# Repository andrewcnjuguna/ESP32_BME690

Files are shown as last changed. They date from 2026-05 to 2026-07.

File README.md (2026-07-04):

# ESP32_BME690

Multi-room ESP32-S3 environmental sensor node that streams air-quality data
to a Node.js server over Wi-Fi. Built around the Bosch BME690 with auxiliary
light, sound and battery monitoring.

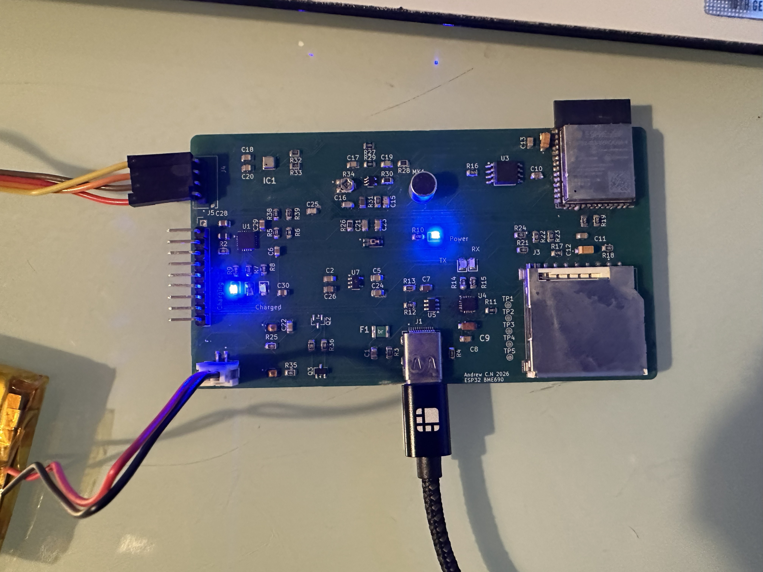
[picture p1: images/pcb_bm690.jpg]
PCB


## Hardware

- ESP32-S3-WROOM-1 module
- Bosch **BME690** (I2C) — temperature, humidity, pressure, IAQ, CO2eq, bVOC
- SH1106 0.96" OLED (I2C)
- TEMT6000 ambient light sensor
- Analog MEMS microphone (sound level)
- 1-cell LiPo with 1M/1M voltage divider on the battery rail
- USB-C power / programming
- Status LED

KiCad project lives in [hardware/kicad/](hardware/kicad/).

### Pin map

| Function | GPIO |
|---|---|
| I2C SDA | 8 |
| I2C SCL | 9 |
| Status LED  | 2 |
| Light sensor (TEMT6000) | 5 |
| Microphone  | 4 |
| VBAT sense  | 1 |

## Firmware

Sketches live in [firmware/](firmware/).

- `ESP32_BME690_usb/` — main node firmware
- `battery_level/`, `light_sensor_test/`, `sound_sensor/` — bring-up sketches

### Setup

1. Open `firmware/ESP32_BME690_usb/` in the Arduino IDE.
2. Copy `secrets.h.example` → `secrets.h` and fill in your Wi-Fi credentials
   and server URL. `secrets.h` is gitignored.
3. Install required libraries: `Adafruit GFX`, `Adafruit SH110X`,
   `BSEC2` (Bosch), `ArduinoJson`, `ArduinoOTA`.
4. Build & flash. The `locationID` constant in the sketch tags this node's
   data on the server (e.g. `Kitchen`, `Living_Room`).

### Node web page (port 80)

Each node runs its own tiny status page at `http://<node-ip>/`
(auto-refreshes every 5 s). It shows the live BSEC readings, light / sound /
battery, **WiFi signal** (RSSI in dBm, an approximate 0–100 % quality, and a
label Excellent/Good/Fair/Weak/Poor), and the SD-log status. If the SD card
is mounted it also links `http://<node-ip>/datalog.csv` to download the full
log.

The node's IP is printed on the serial console at boot
(`[INFO] Web UI at http://...`).

WiFi is self-healing: if the router is down at boot (or the link drops
later), the node keeps logging to SD and retries the connection every 30 s
in the background; OTA and the web page start automatically as soon as the
first connection succeeds — no reboot needed.

### Data upload

Every 3 s BSEC cycle the node POSTs a JSON snapshot to `SERVER_URL`
(`/sensor-data` on the dashboard server). The payload includes `location`,
all sensor channels, and the WiFi link quality (`rssi` in dBm plus a derived
`wifiPercent`). Nodes running older firmware simply omit the WiFi fields —
the dashboard shows "not reported (update firmware)" for them.

## Server (dashboard)

A small Node/Express app in [server/](server/) collects POSTs from each node
and serves a per-room dashboard.

```bash
cd server
npm install express
node server.js
```

Then point a browser at `http://<host>:3000`.

- `POST /sensor-data` — nodes push their JSON snapshot here.
- `GET /data` — latest snapshot of every room, as JSON.
- `GET /` — dashboard. Room boxes are created dynamically from whatever
  `location` tags have reported, so adding a node needs **no server change**.
  Each box shows the air-quality channels plus battery and WiFi signal
  quality for that node.

The `pi_server` notes file documents the systemd / iptables setup used on
the home Raspberry Pi.

## Data logging & plotting

### SD card log

The node averages its 3 s BSEC samples and appends **one CSV row per minute**
to `/datalog.csv` on the SD card:

```
boot_id,uptime_s,epoch,synced,temp_c,hum_pct,press_hpa,iaq,iaq_acc,
co2_ppm,voc_ppm,lux,sound_db,sound_avg,sound_peak,batt_v,batt_pct
```

- `boot_id` — power-session counter (persisted in EEPROM), groups rows from
  one uninterrupted run.
- `uptime_s` — seconds since boot (monotonic, rollover-safe).
- `epoch` / `synced` — Unix time and whether NTP had synced when the row was
  written. Rows logged *before* the sync have `epoch=0`, but their true time
  is still recoverable (see below).
- `iaq_acc` — BSEC accuracy 0–3; air-quality values below your chosen
  threshold are warm-up noise.

Grab the file over WiFi from `http://<node-ip>/datalog.csv`, or pull the
card.

### Plotting with `analysis/plot_datalog.py`

```bash
pip install pandas matplotlib
python analysis/plot_datalog.py datalog.csv            # plot a local file
python analysis/plot_datalog.py --ip 192.168.0.65      # fetch straight from the node
python analysis/plot_datalog.py datalog.csv -o out.png # save instead of showing
python analysis/plot_datalog.py datalog.csv --last 48  # last 48 h only
python analysis/plot_datalog.py datalog.csv --min-accuracy 3  # strict AQ filter
```

The script produces six stacked, time-aligned panels: temp+humidity,
pressure, IAQ, CO₂eq+VOCeq, light+sound, and battery. Under the hood it:

1. **Reconstructs absolute time.** For each `boot_id` it derives
   `boot_epoch = epoch − uptime_s` from the NTP-synced rows, then stamps
   *every* row of that session as `boot_epoch + uptime_s` — so even rows
   logged before the NTP sync get correct timestamps. Sessions that never
   synced have no time anchor and are dropped with a warning.
2. **Masks warm-up air-quality data.** IAQ/CO₂/VOC are blanked where
   `iaq_acc < --min-accuracy` (default 1) so BSEC's calibration period
   doesn't draw misleading flat lines.
3. **Breaks lines at gaps.** Rows are minutely, so a jump larger than
   `--gap-min` (default 5 min) means the node was off; a NaN break is
   inserted so downtime shows as a blank gap instead of a false straight
   line across it.

## Repo layout

```
firmware/   Arduino sketches (main + bring-up)
server/     Node/Express dashboard
analysis/   plot_datalog.py — CSV log plotting
hardware/   KiCad project + design notes
images/     PCB photos
```

Component datasheets are kept locally only (not redistributable).

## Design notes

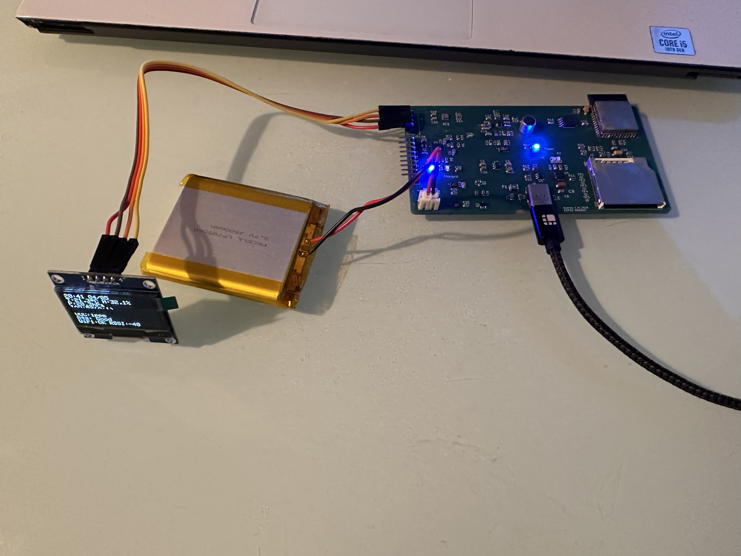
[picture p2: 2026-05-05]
images/pcb_bm690_1.jpg

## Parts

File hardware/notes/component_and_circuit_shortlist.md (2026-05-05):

# Component and reference-circuit shortlist

## Project intent
Multi-room ESP32-based environmental sensor nodes that report to a Raspberry Pi server over Wi-Fi. First board should be reliable, easy to bring up, and suitable for later GitHub publication.

## Core design direction
- MCU/module: **ESP32-S3-WROOM-1**
- Main environmental sensor: **BME690**
- Connectivity: **Wi-Fi**
- Recommended messaging: **MQTT**
- Power: **USB-C + 1-cell LiPo support**
- User feedback: **small display + status LED(s)**

---

# 1. Main components

## 1.1 MCU
### Recommended
- **ESP32-S3-WROOM-1**

### Why
- good mainstream ESP32 module for a fresh PCB
- enough headroom for future firmware growth
- strong support ecosystem
- good for Wi-Fi sensor nodes around the house
- better long-term choice than older ESP32-WROOM-32 for a new board

### Circuit block to include
- EN reset circuit
- GPIO0 boot/programming circuit
- required decoupling near module supply pins
- antenna keepout and module placement rules
- USB/UART or native USB support depending on final programming choice

---

## 1.2 Environmental sensor
### Chosen
- **BME690**

### Why
- better low-power behavior than BME688
- better humidity response time
- more robust, especially for high-condensation applications
- supports future AI/gas-scanner exploration

### Recommended interface
- **I2C** for v1

### Circuit block to include
- 3.3 V supply
- local decoupling capacitor(s) close to the sensor
- I2C pull-ups on SDA/SCL
- optional address selection handling if needed
- careful placement away from heat sources and regulators
- venting / exposure considerations in the PCB and enclosure

### Design note
Do not place the BME690 too close to:
- ESP32 module
- charger IC
- regulator
- display backlight / high-current LED sources

---

# 2. Power architecture

## 2.1 USB-C input
### Recommendation
- USB-C used primarily as **5 V power input** and optionally for data/programming

### Circuit block to include
- USB-C receptacle
- **5.1 kΩ CC resistors** on CC1 and CC2 for sink mode if used as a power sink
- ESD protection on USB data lines if data is exposed
- input bulk capacitance
- reverse / surge / transient protection as appropriate

### Note
For v1, keep USB-C simple. Do not overcomplicate with full PD negotiation unless there is a real need.

---

## 2.2 Battery support
### Recommendation
- **1-cell LiPo / Li-ion** support

### Why
- common, compact, easy to source
- good match for room sensor nodes
- easier ecosystem than multi-cell battery designs

### Battery connector
- JST-PH style 2-pin connector is a practical starting point

---

## 2.3 Charger / power-path
### Current opinion
Do **not** automatically copy TP4056 just because many hobby boards use it.

### Better design goal
Choose a charger / power-path solution that behaves well when:
- USB is plugged in
- battery is present
- board is running at the same time

### Recommendation direction
Look for a charger/power-path IC that supports:
- single-cell LiPo charging
- system load sharing / power-path management
- USB input friendliness
- simple implementation for KiCad v1

### If simplicity wins over elegance
A TP4056-style design can still work for a first version, but it is not my preferred final direction.

### Circuit block to include
- charger IC
- charge current programming resistor
- battery connector
- battery protection strategy
- power-path / system rail handling
- charge status outputs if useful for LEDs or firmware input

---

## 2.4 3.3 V rail
### Recommendation
- stable 3.3 V regulator sized for:
  - ESP32 Wi-Fi bursts
  - sensor load
  - display load
  - future small peripherals

### Circuit block to include
- regulator input/output caps per datasheet
- enough current headroom for Wi-Fi bursts
- attention to thermal behavior

---

# 3. Programming and debug

## Recommendation
For v1, strongly consider a **simple and boring programming path**.

### Two possible directions
#### Option A. Native USB on ESP32-S3
Pros:
- fewer parts
- modern
- convenient

Cons:
- requires careful implementation and confidence in bring-up

#### Option B. Dedicated USB-UART bridge
Pros:
- very familiar and forgiving
- easier bring-up for many first boards

Cons:
- extra IC and routing

### My practical recommendation
If you want the first board to be easier to debug, a **USB-UART bridge** is still a very reasonable choice.
If you want a cleaner modern design and are comfortable with ESP32-S3 native USB, that is also valid.

### Required circuit blocks either way
- EN/reset handling
- BOOT/GPIO0 handling
- programming header or exposed test pads
- optional serial debug pads

---

# 4. Display recommendation

## You definitely want a display
I agree. A local display makes the node much more useful for:
- quick room readings
- setup and debugging
- offline confidence during bring-up

## Recommendation for v1
### Small monochrome I2C OLED
- e.g. **0.96 inch or 1.3 inch SSD1306/SH1106 class display**

### Why
- very common
- easy libraries
- low pin count over I2C
- low complexity
- good enough for temp/humidity/air quality/status

## Alternative
### Small low-power memory LCD or e-paper
Good for battery life, but adds complexity and is less convenient for a first board.

## Recommendation on using your current display
If your current display is already well understood and easy to source, reusing it is totally reasonable. For v1, reusing known-good parts is smart.

### My vote
- If current display is already stable and you like it: **reuse it**
- If not: choose a **small I2C OLED** for the first PCB

---

# 5. Extra sensors worth considering

## 5.1 Sound sensor / microphone
### Yes, this makes sense
Potential uses:
- monitor room noise levels
- detect when a room is unusually loud
- baby room monitoring triggers
- general comfort/quietness indicators

### Important distinction
There are two design levels here:

#### Level 1: sound level only
- easier
- enough for “too loud” detection
- usually the right first step

#### Level 2: event classification (crying, patterns, etc.)
- much harder
- may need better mic, DSP, firmware work, and privacy thinking

### Recommendation
For v1, add a **simple digital MEMS microphone or sound-level-capable mic front end** only if you are comfortable with the added complexity.
Otherwise, leave a footprint/header option for v2.

### My opinion
It makes sense, but I would avoid turning v1 into an audio-analysis board unless that is a top priority.

---

## 5.2 Other useful sensors to consider
### Light sensor
Useful for room context and automation.
Low complexity. Good optional add.

### PIR / occupancy / motion
Useful if you want room context, but depends on enclosure and placement.
Probably better as a later revision unless occupancy is core.

### CO2-specific sensor
If accurate CO2 is a major goal, consider a dedicated CO2 sensor later. BME690-derived CO2eq is useful, but not the same as a true NDIR CO2 reading.

---

# 6. Recommended v1 scope
To keep the first PCB sane, I recommend:
- ESP32-S3-WROOM-1
- BME690
- USB-C
- 1-cell LiPo support
- stable charger/power path
- 3.3 V regulator
- small display
- status LED
- optional expansion header

## Things I would defer unless strongly needed now
- advanced audio classification
- too many extra sensors
- fancy battery fuel gauging
- full USB-C complexity beyond what you actually need

---

# 7. Immediate next decisions
1. Pick display strategy
   - reuse current display, or
   - small I2C OLED
2. Decide whether sound sensing is:
   - required for v1, or
   - optional / reserved for v2
3. Choose charger/power-path philosophy
   - simplest workable, or
   - slightly more polished modern solution
4. Decide programming path
   - native USB on ESP32-S3, or
   - USB-UART bridge

---

# 8. My current v1 recommendation
If I were optimizing for a successful first PCB, I would build:
- **ESP32-S3-WROOM-1**
- **BME690 over I2C**
- **small I2C OLED display**
- **USB-C power/programming**
- **1-cell LiPo support**
- **status LED**
- **leave microphone as optional or v2 unless it is a core requirement**

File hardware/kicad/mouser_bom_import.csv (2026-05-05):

Manufacturer Part Number | Quantity
BME690 | 1
0ZCH0110AF2E | 1
FBMJ2125HM330-T | 1
SS-52400-002 | 1
B2B-PH-SM4-TB | 1
GSD090012SEU | 1
B4B-XH-AM(LF)(SN) | 1
CMC-5042PF-AC | 1
TEMT6000X01 | 1
BC817 | 2
35WR100KLFTR | 1
USLPT2819DT2TR | 2
MCP73871 | 1
ESP32-S3-WROOM-1 | 1
W25Q32JVSSIQ | 1
CP2102N-A01-GQFN20 | 1
USBLC6-2SC6 | 1
MAX4466EXK | 1
AP2112K-3.3 | 1
T491A106K016AT | 2
T491A475K016AT | 1

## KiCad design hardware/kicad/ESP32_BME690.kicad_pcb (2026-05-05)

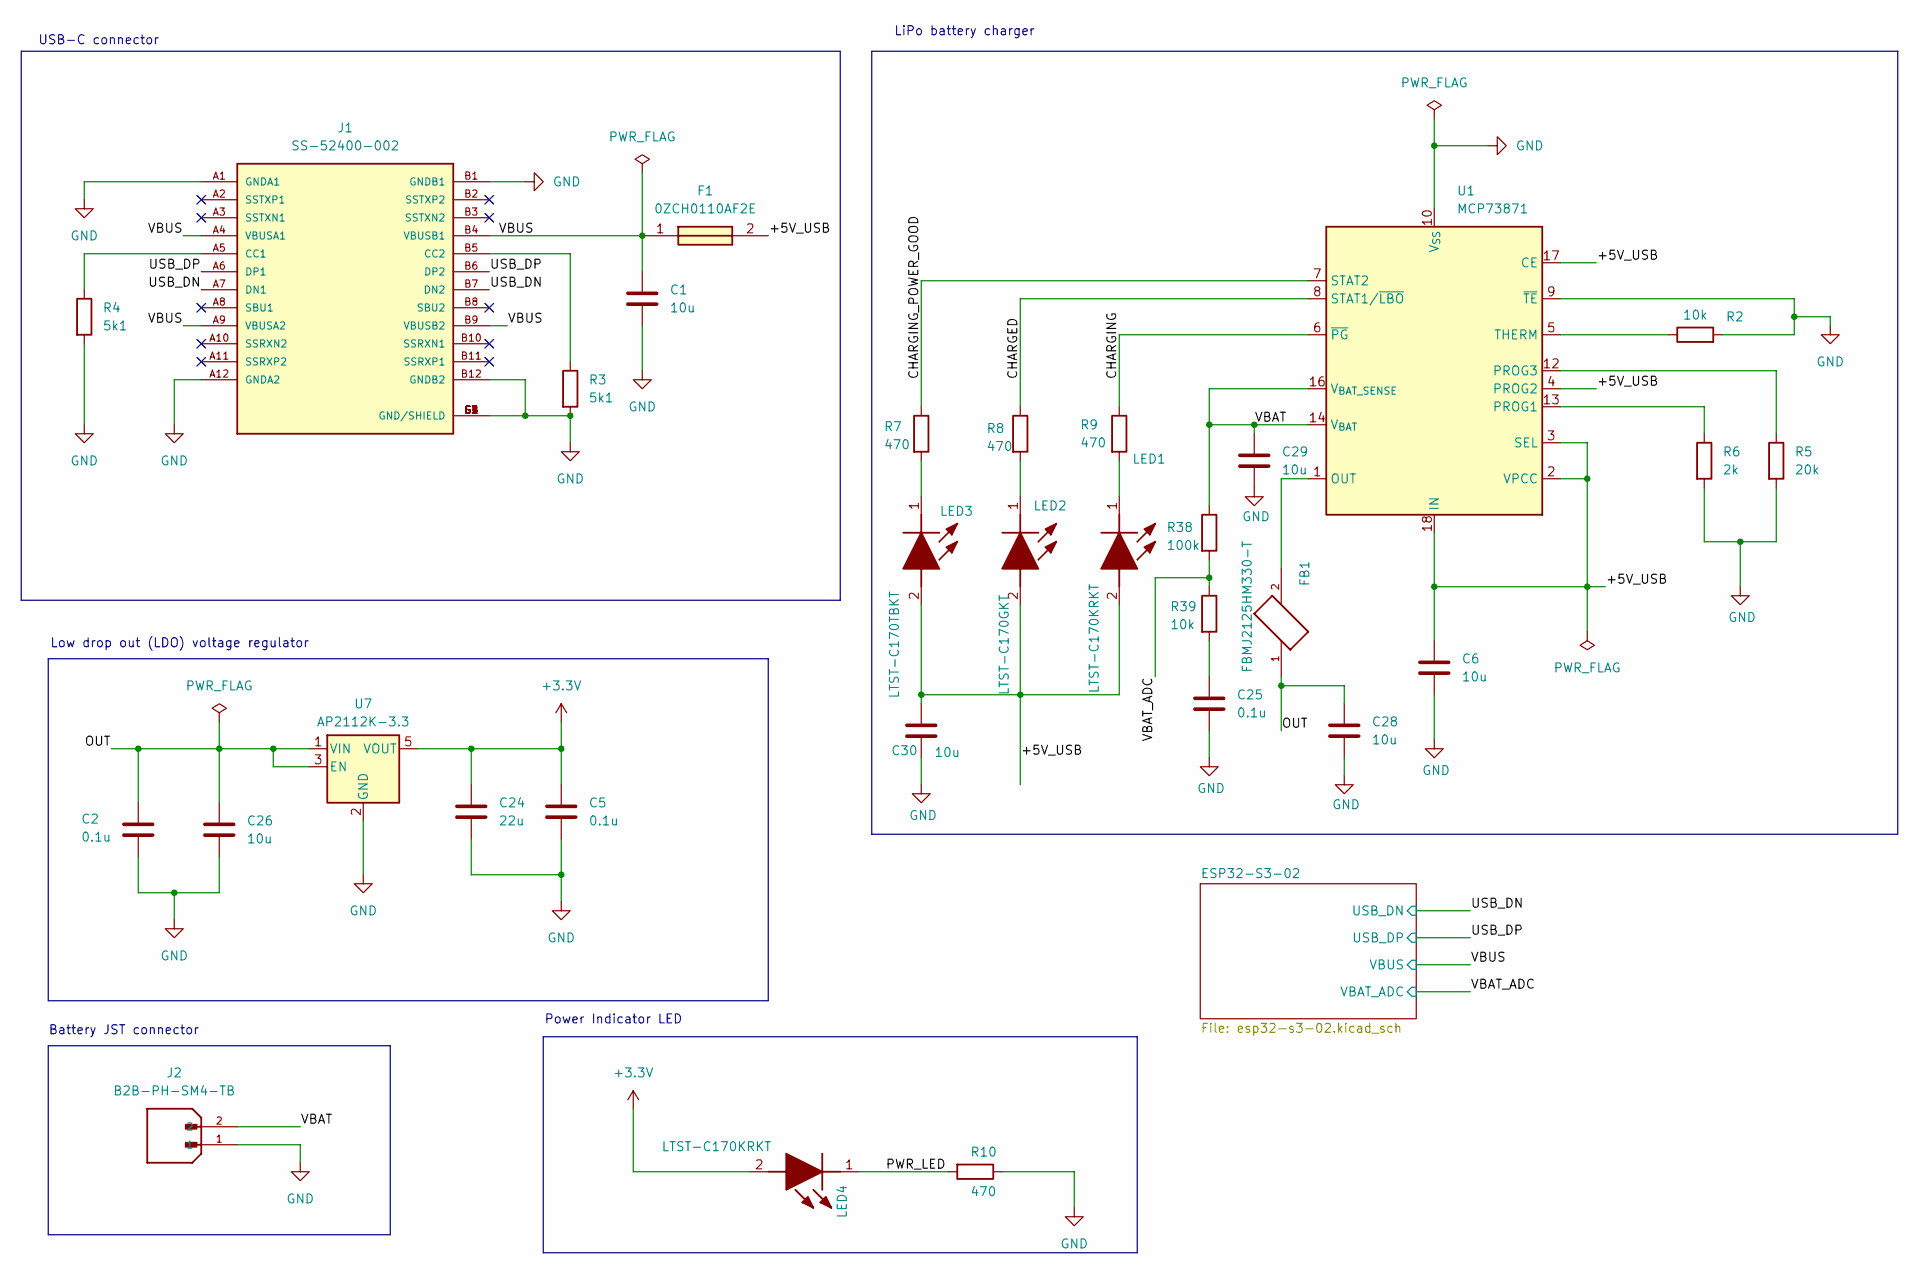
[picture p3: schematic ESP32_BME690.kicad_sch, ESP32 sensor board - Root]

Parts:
C1, C6, C26, C28, C29, C30: 10u; C_0805_2012Metric
C2, C5, C25: 0.1u; C_0805_2012Metric
C24: 22u; C_0805_2012Metric
F1: 0ZCH0110AF2E; FUSC3226X100N; Manufacturer_Part_Number 0ZCH0110AF2E
FB1: FBMJ2125HM330-T; BEADC2012X105N
J1: SS-52400-002; BELFUSE_SS-52400-002; PARTREV A0
J2: B2B-PH-SM4-TB; JST_B2B-PH-SM4-TB; PARTREV N/A
LED1, LED4: LTST-C170KRKT; LEDC2012X120N; Manufacturer_Part_Number LTST-C170KRKT; Mouser Part Number 859-LTST-C170KRKT
LED2: LTST-C170GKT; LEDC2012X120N; Manufacturer_Part_Number LTST-C170GKT; Mouser Part Number 859-LTST-C170GKT
LED3: LTST-C170TBKT; LEDC2012X120N; Manufacturer_Part_Number LTST-C170TBKT; Mouser Part Number 859-LTST-C170TBKT
R2, R39: 10k; R_0805_2012Metric
R3, R4: 5k1; R_0805_2012Metric
R5: 20k; R_0805_2012Metric
R6: 2k; R_0805_2012Metric
R7, R8, R9, R10: 470; R_0805_2012Metric
R38: 100k; R_0805_2012Metric
U1: MCP73871; QFN-20-1EP_4x4mm_P0.5mm_EP2.5x2.5mm
U7: AP2112K-3.3; SOT-23-5

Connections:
+3.3V: C5.1, C24.1, LED4.2 (A), U7.5 (VOUT); also elsewhere on the board
/+5V_USB: C6.1, C30.1, F1.2, LED1.2 (A), LED2.2 (A), LED3.2 (A), U1.2 (VPCC), U1.3 (SEL), U1.4 (PROG2), U1.17 (CE), U1.18 (IN), U1.19 (IN)
/CHARGED: R8.1, U1.8 (STAT1/~LBO)
/CHARGING: R9.1, U1.6 (~PG)
/CHARGING_POWER_GOOD: R7.1, U1.7 (STAT2)
/OUT: C2.1, C26.1, C28.1, FB1.1, U7.1 (VIN), U7.3 (EN)
/PWR_LED: LED4.1 (K), R10.2
/USB_DN: J1.A7 (DN1), J1.B7 (DN2); also elsewhere on the board
/USB_DP: J1.A6 (DP1), J1.B6 (DP2); also elsewhere on the board
/VBAT: C29.1, J2.2, R38.1, U1.14 (V_{BAT}), U1.15 (V_{BAT}), U1.16 (V_{BAT_SENSE})
/VBAT_ADC: R38.2, R39.1; also elsewhere on the board
/VBUS: C1.1, F1.1, J1.A4 (VBUSA1), J1.A9 (VBUSA2), J1.B4 (VBUSB1), J1.B9 (VBUSB2); also elsewhere on the board
GND: C1.2, C2.2, C5.2, C6.2, C24.2, C25.2, C26.2, C28.2, C29.2, C30.2, J1.A1 (GNDA1), J1.A12 (GNDA2), J1.B1 (GNDB1), J1.B12 (GNDB2), J1.G1 (GND/SHIELD), J1.G2 (GND/SHIELD), J1.G3 (GND/SHIELD), J1.G4 (GND/SHIELD), J1.S1 (GND/SHIELD), J1.S2 (GND/SHIELD), J1.S3 (GND/SHIELD), J1.S4 (GND/SHIELD), J2.1, R2.2, R3.2, R4.2, R5.2, R6.2, R10.1, U1.9 (~TE), U1.10 (V_{SS}), U1.11 (V_{SS}), U1.21 (V_{SS}), U7.2 (GND); also elsewhere on the board
unnamed: C25.1, R39.2
unnamed: FB1.2, U1.1 (OUT), U1.20 (OUT)
unnamed: J1.A5 (CC1), R4.1
unnamed: J1.B5 (CC2), R3.1
unnamed: LED1.1 (K), R9.2
unnamed: LED2.1 (K), R8.2
unnamed: LED3.1 (K), R7.2
unnamed: R6.1, U1.13 (PROG1)
unnamed: R5.1, U1.12 (PROG3)
unnamed: R2.1, U1.5 (THERM)

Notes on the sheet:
Battery JST connector
LiPo battery charger
Power Indicator LED
USB-C connector
Low drop out (LDO) voltage regulator

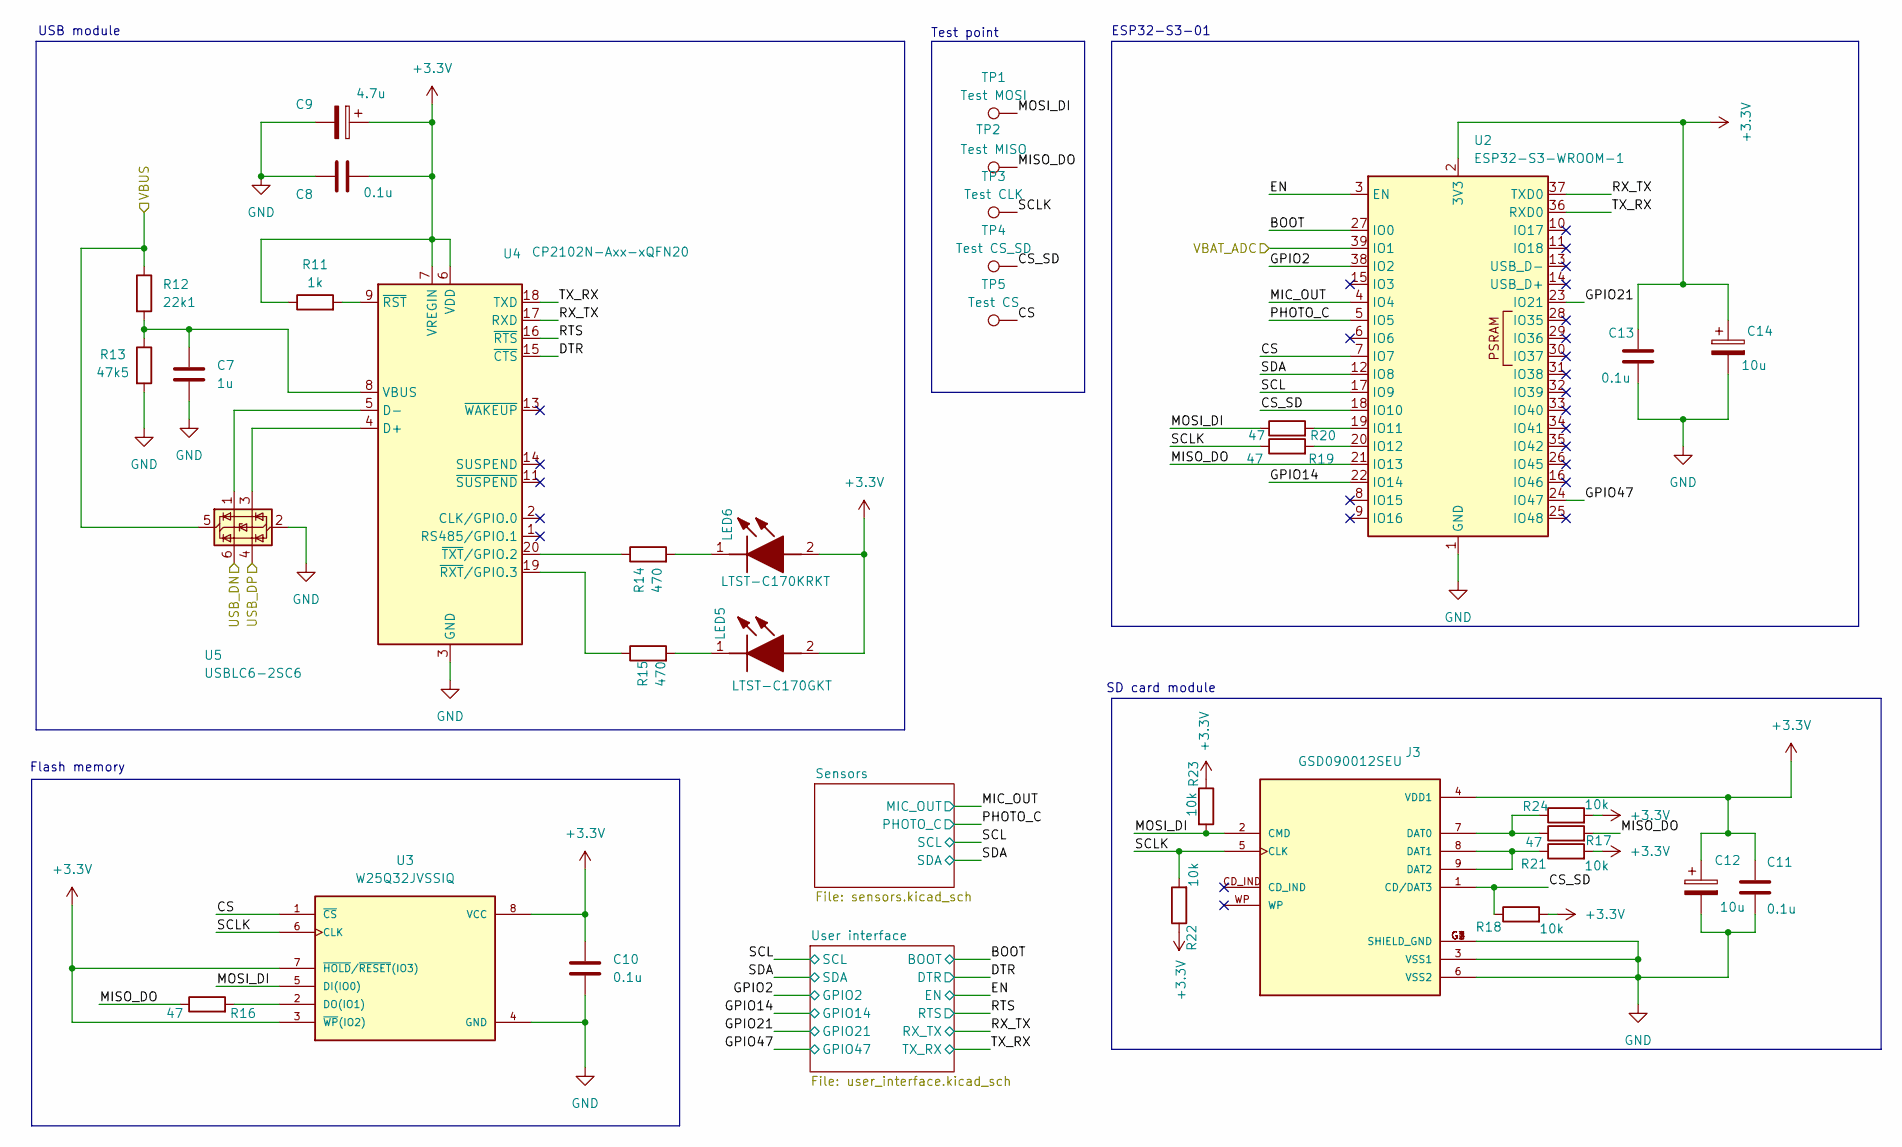
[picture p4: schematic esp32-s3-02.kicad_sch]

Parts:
C7: 1u; C_0805_2012Metric
C8, C10, C11, C13: 0.1u; C_0805_2012Metric
C9: 4.7u; T491A
C12, C14: 10u; T491A
J3: GSD090012SEU; AMPHENOL_GSD090012SEU; PARTREV E
LED5: LTST-C170GKT; LEDC2012X120N; Manufacturer_Part_Number LTST-C170GKT; Mouser Part Number 859-LTST-C170GKT
LED6: LTST-C170KRKT; LEDC2012X120N; Manufacturer_Part_Number LTST-C170KRKT; Mouser Part Number 859-LTST-C170KRKT
R11: 1k; R_0805_2012Metric
R12: 22k1; R_0805_2012Metric
R13: 47k5; R_0805_2012Metric
R14, R15: 470; R_0805_2012Metric
R16, R17, R19, R20: 47; R_0805_2012Metric
R18, R21, R22, R23, R24: 10k; R_0805_2012Metric
TP1: Test MOSI; TestPoint_Pad_D1.0mm
TP2: Test MISO; TestPoint_Pad_D1.0mm
TP3: Test CLK; TestPoint_Pad_D1.0mm
TP4: Test CS_SD; TestPoint_Pad_D1.0mm
TP5: Test CS; TestPoint_Pad_D1.0mm
U2: ESP32-S3-WROOM-1
U3: W25Q32JVSSIQ; SOIC127P790X216-8N; M_PART_NUMBER W25QXX
U4: CP2102N-Axx-xQFN20; SiliconLabs_QFN-20-1EP_3x3mm_P0.5mm_EP1.8x1.8mm
U5: USBLC6-2SC6; SOT-23-6

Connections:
+3.3V: C8.2, C9.1, C10.1, C11.1, C12.1, C13.1, C14.1, J3.4 (VDD1), LED5.2 (A), LED6.2 (A), R11.1, R18.2, R21.2, R22.1, R23.1, R24.2, U2.2 (3V3), U3.3 (~WP(IO2)), U3.7 (~HOLD/~RESET(IO3)), U3.8 (VCC), U4.6 (VDD), U4.7 (VREGIN); also elsewhere on the board
/ESP32-S3-02/BOOT: U2.27 (IO0); also elsewhere on the board
/ESP32-S3-02/CS: TP5.1 (1_1), U2.7 (IO7), U3.1 (~CS)
/ESP32-S3-02/CS_SD: J3.1 (CD/DAT3), R18.1, TP4.1 (1_1), U2.18 (IO10)
/ESP32-S3-02/DTR: U4.15 (~CTS); also elsewhere on the board
/ESP32-S3-02/EN: U2.3 (EN); also elsewhere on the board
/ESP32-S3-02/GPIO2: U2.38 (IO2); also elsewhere on the board
/ESP32-S3-02/GPIO14: U2.22 (IO14); also elsewhere on the board
/ESP32-S3-02/GPIO21: U2.23 (IO21); also elsewhere on the board
/ESP32-S3-02/GPIO47: U2.24 (IO47); also elsewhere on the board
/ESP32-S3-02/MIC_OUT: U2.4 (IO4); also elsewhere on the board
/ESP32-S3-02/MISO_DO: R16.1, R17.2, TP2.1 (1_1), U2.21 (IO13)
/ESP32-S3-02/MOSI_DI: J3.2 (CMD), R20.1, R23.2, TP1.1 (1_1), U3.5 (DI(IO0))
/ESP32-S3-02/PHOTO_C: U2.5 (IO5); also elsewhere on the board
/ESP32-S3-02/RTS: U4.16 (~RTS); also elsewhere on the board
/ESP32-S3-02/RX_TX: U2.37 (TXD0), U4.17 (RXD); also elsewhere on the board
/ESP32-S3-02/SCL: U2.17 (IO9); also elsewhere on the board
/ESP32-S3-02/SCLK: J3.5 (CLK), R19.1, R22.2, TP3.1 (1_1), U3.6 (CLK)
/ESP32-S3-02/SDA: U2.12 (IO8); also elsewhere on the board
/ESP32-S3-02/TX_RX: U2.36 (RXD0), U4.18 (TXD); also elsewhere on the board
/USB_DN: U5.6 (I/O1); also elsewhere on the board
/USB_DP: U5.4 (I/O2); also elsewhere on the board
/VBAT_ADC: U2.39 (IO1); also elsewhere on the board
/VBUS: R12.1, U5.5 (VBUS); also elsewhere on the board
GND: C7.2, C8.1, C9.2, C10.2, C11.2, C12.2, C13.2, C14.2, J3.3 (VSS1), J3.6 (VSS2), J3.G1 (SHIELD_GND), J3.G2 (SHIELD_GND), J3.G3 (SHIELD_GND), J3.G4 (SHIELD_GND), R13.2, U2.1 (GND), U2.40 (GND), U2.41 (GND), U3.4 (GND), U4.3 (GND), U4.12 (GND), U4.21 (GND), U5.2 (GND); also elsewhere on the board
unnamed: J3.7 (DAT0), R17.1, R24.1
unnamed: J3.8 (DAT1), J3.9 (DAT2), R21.1
unnamed: LED5.1 (K), R15.2
unnamed: LED6.1 (K), R14.2
unnamed: R20.2, U2.19 (IO11)
unnamed: R19.2, U2.20 (IO12)
unnamed: R16.2, U3.2 (DO(IO1))
unnamed: U4.4 (D+), U5.3 (I/O2)
unnamed: U4.5 (D-), U5.1 (I/O1)
unnamed: C7.1, R12.2, R13.1, U4.8 (VBUS)
unnamed: R11.2, U4.9 (~RST)
unnamed: R15.1, U4.19 (~RXT/GPIO.3)
unnamed: R14.1, U4.20 (~TXT/GPIO.2)

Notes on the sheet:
ESP32-S3-01
Flash memory
SD card module
USB module
Test point

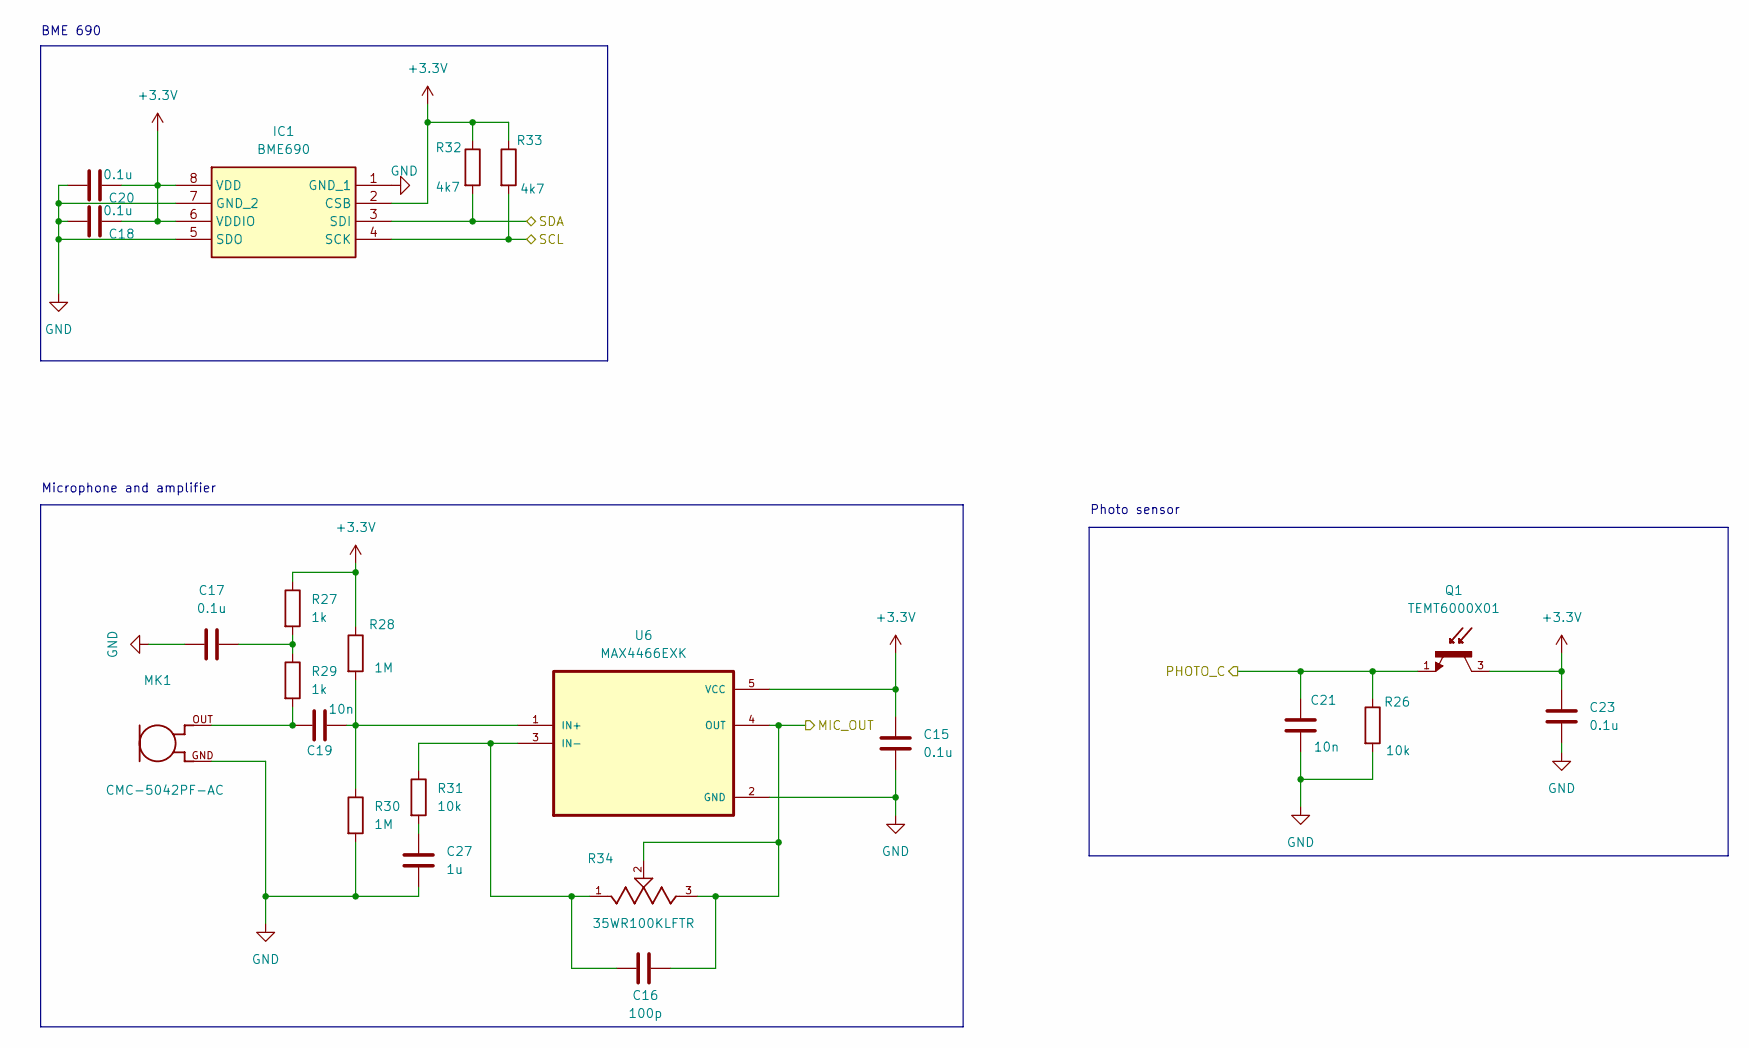
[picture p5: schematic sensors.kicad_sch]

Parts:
C15, C17, C18, C20, C23: 0.1u; C_0805_2012Metric
C16: 100p; C_0805_2012Metric
C19, C21: 10n; C_0805_2012Metric
C27: 1u; C_0805_2012Metric
IC1: BME690; Manufacturer_Part_Number BME690; Mouser Part Number 262-BME690
MK1: CMC-5042PF-AC; CUI_CMC-5042PF-AC
Q1: TEMT6000X01; TRANS_TEMT6000X01; PARTREV 1.9
R26, R31: 10k; R_0805_2012Metric
R27, R29: 1k; R_0805_2012Metric
R28, R30: 1M; R_0805_2012Metric
R32, R33: 4k7; R_0805_2012Metric
R34: 35WR100KLFTR; TRIM_35WR100KLFTR; PARTREV D
U6: MAX4466EXK; SOT65P210X110-5N

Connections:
+3.3V: C15.1, C18.1, C20.1, C23.1, IC1.2 (CSB), IC1.6 (VDDIO), IC1.8 (VDD), Q1.3, R27.1, R28.1, R32.1, R33.1, U6.5 (VCC); also elsewhere on the board
/ESP32-S3-02/MIC_OUT: C16.2, R34.2, R34.3, U6.4 (OUT); also elsewhere on the board
/ESP32-S3-02/PHOTO_C: C21.1, Q1.1, R26.1; also elsewhere on the board
/ESP32-S3-02/SCL: IC1.4 (SCK), R33.2; also elsewhere on the board
/ESP32-S3-02/SDA: IC1.3 (SDI), R32.2; also elsewhere on the board
GND: C15.2, C17.1, C18.2, C20.2, C21.2, C23.2, C27.1, IC1.1 (GND_1), IC1.5 (SDO), IC1.7 (GND_2), MK1.GND, R26.2, R30.2, U6.2 (GND); also elsewhere on the board
unnamed: C17.2, R27.2, R29.1
unnamed: C19.1, MK1.OUT, R29.2
unnamed: C27.2, R31.2
unnamed: C19.2, R28.2, R30.1, U6.1 (IN+)
unnamed: C16.1, R31.1, R34.1, U6.3 (IN-)

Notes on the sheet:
BME 690
Microphone and amplifier
Photo sensor

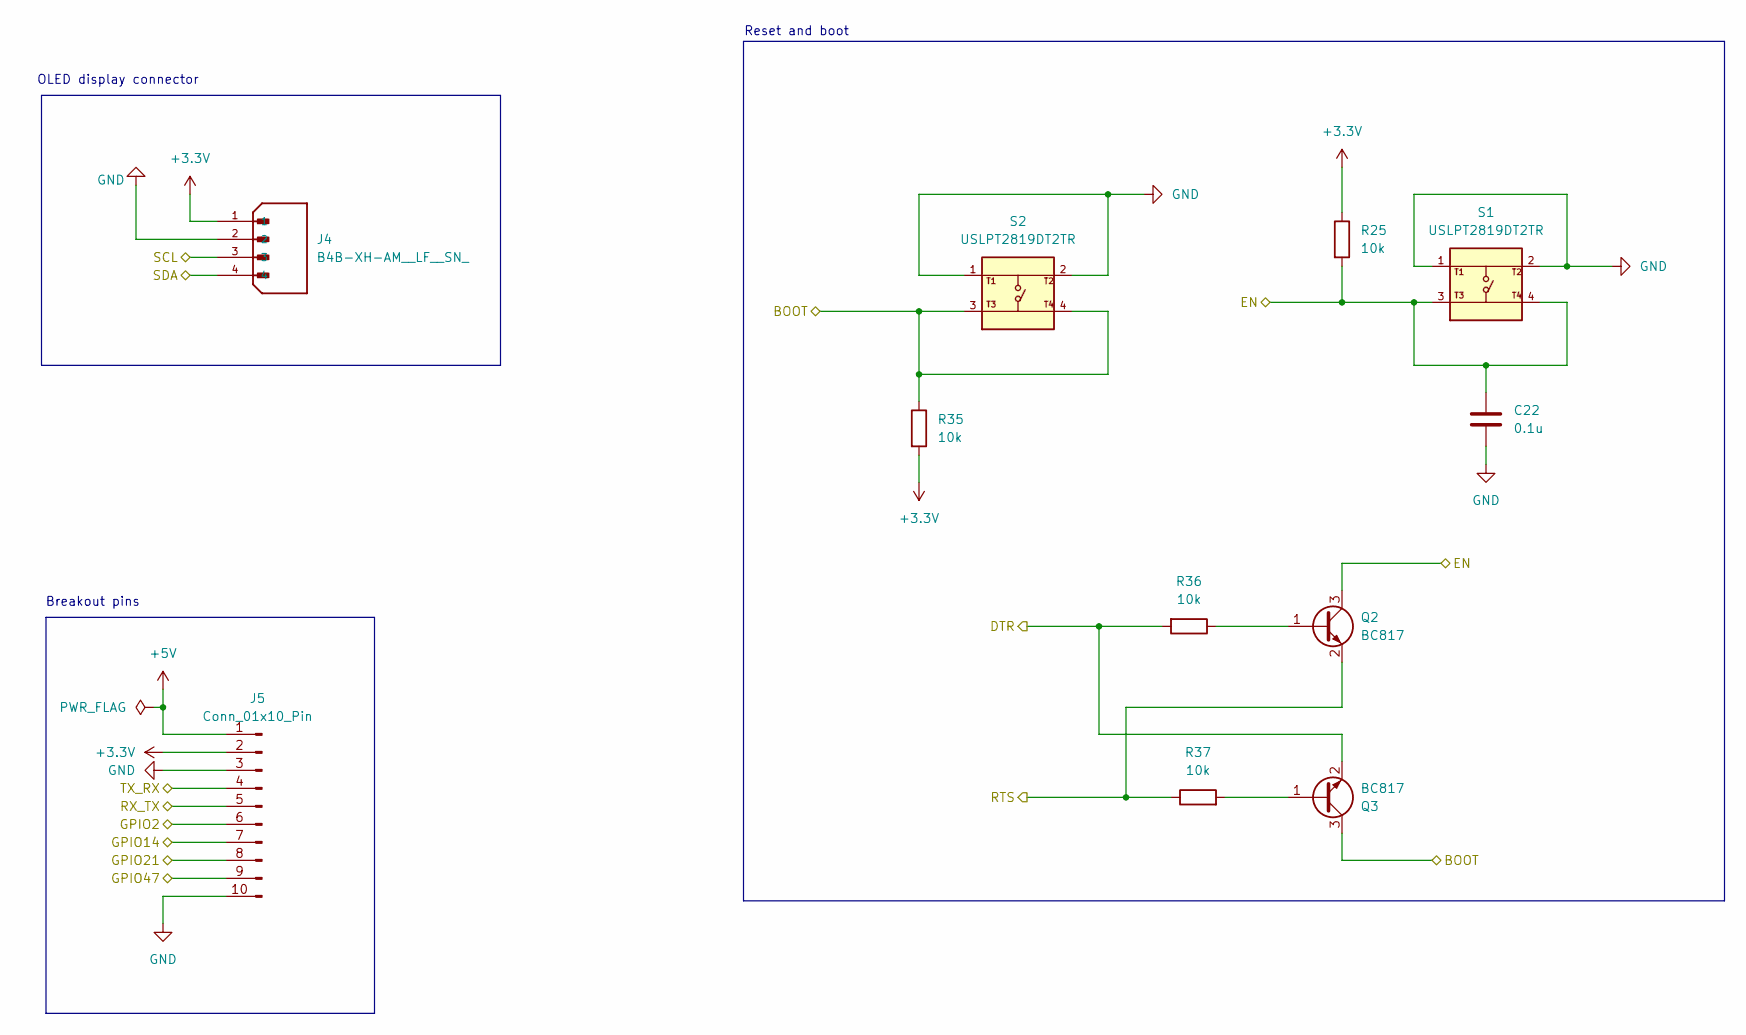
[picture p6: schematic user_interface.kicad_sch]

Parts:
C22: 0.1u; C_0805_2012Metric
J4: B4B-XH-AM__LF__SN_; JST_B4B-XH-AM__LF__SN_; PARTREV N/A
J5: Conn_01x10_Pin; PinHeader_1x10_P2.54mm_Vertical
Q2, Q3: BC817; SOT-23
R25, R35, R36, R37: 10k; R_0805_2012Metric
S1, S2: USLPT2819DT2TR; SW_USLPT2819DT2TR; PARTREV P

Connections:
+3.3V: J4.1, J5.2, R25.1, R35.2; also elsewhere on the board
+5V: J5.1
/ESP32-S3-02/BOOT: Q3.3 (C), R35.1, S2.3, S2.4; also elsewhere on the board
/ESP32-S3-02/DTR: Q3.2 (E), R36.2; also elsewhere on the board
/ESP32-S3-02/EN: C22.1, Q2.3 (C), R25.2, S1.3, S1.4; also elsewhere on the board
/ESP32-S3-02/GPIO2: J5.6; also elsewhere on the board
/ESP32-S3-02/GPIO14: J5.7; also elsewhere on the board
/ESP32-S3-02/GPIO21: J5.8; also elsewhere on the board
/ESP32-S3-02/GPIO47: J5.9; also elsewhere on the board
/ESP32-S3-02/RTS: Q2.2 (E), R37.1; also elsewhere on the board
/ESP32-S3-02/RX_TX: J5.5; also elsewhere on the board
/ESP32-S3-02/SCL: J4.3; also elsewhere on the board
/ESP32-S3-02/SDA: J4.4; also elsewhere on the board
/ESP32-S3-02/TX_RX: J5.4; also elsewhere on the board
GND: C22.2, J4.2, J5.3, J5.10, S1.1, S1.2, S2.1, S2.2; also elsewhere on the board
unnamed: Q2.1 (B), R36.1
unnamed: Q3.1 (B), R37.2

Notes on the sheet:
Reset and boot
Breakout pins
OLED display connector

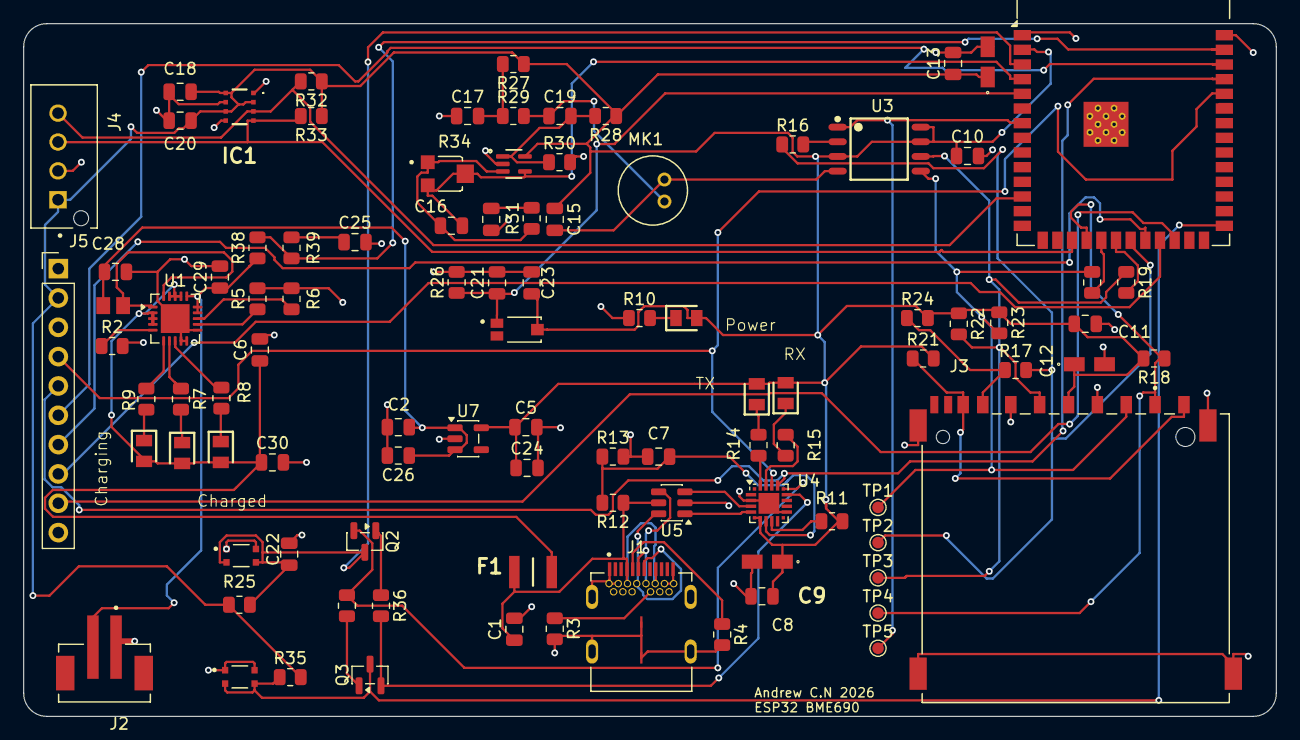
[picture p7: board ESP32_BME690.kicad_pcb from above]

Board: 4 copper layers, 108.5 x 60.0 mm, 98 parts (0 on the bottom side), 62 nets.

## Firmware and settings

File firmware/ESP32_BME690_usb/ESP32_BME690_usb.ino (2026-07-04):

#include <WiFi.h>
#include <WebServer.h>
#include <Wire.h>
#include <Adafruit_GFX.h>
#include <Adafruit_SH110X.h>
#include "time.h"
// BSEC3 + BME690 (bme69x). The BME690 reports variant 0x02, which the old
// BSEC2/BME68x stack mis-reads (garbage pressure). BSEC3 handles it correctly.
#include "bsec_interface.h"
#include "bsec_datatypes.h"
#include "bme69x.h"
#ifndef BSEC_INSTANCE_SIZE
#define BSEC_INSTANCE_SIZE  UINT16_C(3272)   // from Bosch BME690 bsec_integration.h
#endif
#ifndef BSEC_CHECK_INPUT
#define BSEC_CHECK_INPUT(x, shift)  ((x) & (1 << ((shift) - 1)))
#endif
#include <HTTPClient.h>
#include <ArduinoJson.h>
#include <EEPROM.h>
#include <ArduinoOTA.h>
#include <SPI.h>
#include <SD.h>
#include "esp_timer.h"
#include "secrets.h"

// --- Configuration ---
const char* ssid = WIFI_SSID;
const char* password = WIFI_PASSWORD;
const char* serverName = SERVER_URL;

#define SCREEN_WIDTH 128
#define SCREEN_HEIGHT 64
#define OLED_RESET -1
#define I2C_ADDRESS 0x3C

// CORRECTED I2C Pins based on your ESP32-S3 internal labels!
#define SDA_PIN 8
#define SCL_PIN 9

#define ERROR_LED_PIN 2

// Extra sensor pins
#define LIGHT_PIN 5
#define MIC_PIN 4
#define VBAT_ADC_PIN 1
#define BAT_DIVIDER_RATIO 2.0f
#define SOUND_SAMPLE_WINDOW_MS 50

// SD card (SPI). Own bus, independent of the I2C sensors on 8/9.
#define SD_CS   10
#define SD_MOSI 11
#define SD_SCLK 12
#define SD_MISO 13
#define SD_LOG_FILE "/datalog.csv"
// Averaged sample written to the SD card once per this interval.
#define SD_LOG_INTERVAL_MS 60000UL

const char* locationID = "Hallway";
#define OTA_HOSTNAME "esp32-bme690-hallway"

// BSEC State Configuration
#define EEPROM_SIZE (BSEC_MAX_STATE_BLOB_SIZE + 16)
#define BSEC_STATE_EEPROM_ADDR 0
#define BSEC_STATE_MAGIC_NUMBER_ADDR (BSEC_STATE_EEPROM_ADDR + BSEC_MAX_STATE_BLOB_SIZE)
#define BSEC_STATE_VALID_MAGIC 0x42
// Boot counter lives past the BSEC state blob + its magic byte (4 bytes, uint32).
#define BOOT_ID_EEPROM_ADDR (BSEC_STATE_MAGIC_NUMBER_ADDR + 4)
const unsigned long BSEC_STATE_SAVE_INTERVAL_MS = 4 * 60 * 60 * 1000;

// WiFi recovery: OTA + web UI start on the first successful connection (even
// if that happens long after boot) and a reconnect is kicked off while down.
bool netServicesStarted = false;
unsigned long lastWifiRetry = 0;
const unsigned long WIFI_RETRY_INTERVAL_MS = 30000;

// NTP Configuration
const char* ntpServer = "pool.ntp.org";
const char* timeZone = "CET-1CEST,M3.5.0,M10.5.0/3"; 
bool timeSynchronized = false;
unsigned long lastNtpSyncAttempt = 0;

// --- Global Objects ---
Adafruit_SH1106G display(SCREEN_WIDTH, SCREEN_HEIGHT, &Wire, OLED_RESET);
WebServer server(80);

// --- BSEC3 + BME690 driver state ---
extern "C" { extern const uint8_t bsec_config_iaq[]; }   // bme690_iaq_33v_3s_28d blob
static uint8_t  bsecInstanceMem[BSEC_INSTANCE_SIZE];
static void*    bsecInst = bsecInstanceMem;
static uint8_t  bsecWorkBuffer[BSEC_MAX_WORKBUFFER_SIZE];
static int64_t  bsecNextCallNs = 0;
static struct bme69x_dev bme;
static uint8_t  bmeI2cAddr = BME69X_I2C_ADDR_LOW;        // 0x76

// --- Global Variables for Sensor Data ---
String bsecLogString;
const char* currentIAQStatusText = "Initializing...";
uint8_t bsecState[BSEC_MAX_STATE_BLOB_SIZE] = {0};
unsigned long lastBsecStateSaveTime = 0;

// Since BSEC2 uses a callback, we temporarily store values here
float currentTemp = 0, currentHum = 0, currentPress = 0, currentIAQ = 0;
float currentStaticIAQ = 0, currentCO2 = 0, currentVOC = 0;
uint8_t currentIAQAccuracy = 0;
bool newDataAvailable = false;

// Auxiliary sensor readings (light, sound, battery)
float currentLux = 0;
int currentSoundLevel = 0;       // Average peak-to-peak amplitude (sustained loudness)
int currentSoundPeak = 0;        // Loudest single 50ms window in the upload interval
float currentSoundDb = 0;        // 20*log10(avg) — uncalibrated logarithmic level
float currentBatteryVolts = 0;
int currentBatteryPercent = 0;
unsigned long soundWindowStart = 0;
int currentSignalMax = 0;
int currentSignalMin = 4095;
uint32_t soundSumSinceLastUpload = 0;
uint16_t soundCountSinceLastUpload = 0;
int soundPeakSinceLastUpload = 0;

// --- SD data logging ---
bool sdAvailable = false;
uint32_t bootId = 0;
// bootEpoch = wall-clock time (Unix seconds) at uptime 0. Once NTP syncs, this
// lets any row's true time be reconstructed as bootEpoch + uptime, even rows
// written before the sync. Zero until the first successful NTP sync.
time_t bootEpoch = 0;
bool bootEpochValid = false;
unsigned long lastSdLogTime = 0;

// Accumulators for the averaged 60s SD row (summed every 3s BSEC cycle).
struct LogAccum {
  double temp, hum, press, iaq, staticIaq, co2, voc, lux, soundDb, soundAvg;
  double batV, batPct;
  long   soundPeak;
  uint8_t iaqAcc;
  uint16_t n;
} logAccum = {0};

// --- Function Prototypes ---
void setupBsec(void);
void bsec3Run(void);
void handleErrorCondition(void);
void loadBsecState(void);
void saveBsecState(void);
void handleBsecStateSaving(void);
void connectToWiFi(void);
void maintainWiFi(void);
void setupOTA(void);
void setupWebServer(void);
void handleRoot(void);
void handleDownloadLog(void);
int  rssiToPercent(long rssi);
const char* wifiQualityLabel(long rssi);
void setupSD(void);
uint32_t nextBootId(void);
int64_t uptimeSeconds(void);
void accumulateLogSample(void);
void logToSD(void);
void initNTP(void);
void updateNTPTime(void);
void updateAndLogIAQStatusText(void);
void sendSensorDataToServer(void);
void displayDataOnOLED(void);
void printWithLeadingZero(int value);
String buildBsecDebugString(void);
void readLightSensor(void);
void pollSoundSensor(void);
void readBattery(void);
int  getBatteryPercentage(float voltage);
int  mapFloat(float x, float in_min, float in_max, int out_min, int out_max);

// --- Setup ---
void setup() {
  Serial.begin(115200);
  // Wait briefly for a USB host, but never block boot when deployed headless
  // on a plain charger (native-USB S3 keeps !Serial true with no host).
  unsigned long serialWaitStart = millis();
  while (!Serial && millis() - serialWaitStart < 2000) delay(10);
  Serial.println("\n[INFO] Booting up sensor node...");

  pinMode(ERROR_LED_PIN, OUTPUT);
  digitalWrite(ERROR_LED_PIN, LOW);

  pinMode(MIC_PIN, INPUT);
  analogReadResolution(12);
  analogSetAttenuation(ADC_11db);

  Wire.begin(SDA_PIN, SCL_PIN);

  if (!display.begin(I2C_ADDRESS, true)) { 
    Serial.println("[ERROR] SH1106G allocation failed");
    handleErrorCondition();
  }
  Serial.println("[INFO] OLED initialized.");
  display.display(); 
  delay(1000);
  display.clearDisplay();
  display.setTextSize(1);
  display.setTextColor(SH110X_WHITE);
  display.setCursor(0, 0);
  display.println("Initializing...");
  display.display();

  if (!EEPROM.begin(EEPROM_SIZE)) {
    Serial.println("[ERROR] Failed to initialize EEPROM!");
  } else {
    Serial.println("[INFO] EEPROM initialized.");
  }

  // Bump the boot counter (groups a power session in the log) and mount the SD.
  bootId = nextBootId();
  Serial.println("[INFO] Boot ID: " + String(bootId));
  setupSD();

  connectToWiFi();
  maintainWiFi();   // starts OTA + web UI now if the connection already came up

  initNTP();

  // Initialize the BME690 via BSEC3 (forced mode, low-power 3s rate)
  setupBsec();

  Serial.println("[INFO] Setup complete. Starting main loop.");
  display.clearDisplay();
  display.setCursor(0,0);
  display.println("Setup Complete!");
  display.display();
  delay(1000);
}

// --- Main Loop ---
void loop() {
  unsigned long currentTime = millis();

  // 1. Listen to the microphone continuously in the background!
  pollSoundSensor();

  // 2. Step the BSEC3 driver (runs a forced measurement when due).
  bsec3Run();

  // 3. If BSEC data is ready (every 3 seconds)
  if (newDataAvailable) {
    newDataAvailable = false; 

    readLightSensor();
    readBattery();

    // Aggregate the last 3 seconds of 50ms peak-to-peak windows
    if (soundCountSinceLastUpload > 0) {
      currentSoundLevel = soundSumSinceLastUpload / soundCountSinceLastUpload;
    } else {
      currentSoundLevel = 0;
    }
    currentSoundPeak = soundPeakSinceLastUpload;
    currentSoundDb = currentSoundLevel > 0 ? 20.0f * log10f((float)currentSoundLevel) : 0.0f;
    soundSumSinceLastUpload = 0;
    soundCountSinceLastUpload = 0;
    soundPeakSinceLastUpload = 0;

    // The rest of your code remains exactly the same...
    bsecLogString = buildBsecDebugString();
    Serial.println(bsecLogString);

    updateAndLogIAQStatusText();
    sendSensorDataToServer();
    displayDataOnOLED();
    handleBsecStateSaving();

    // Fold this 3s sample into the running average, and flush a row to the
    // SD card once per SD_LOG_INTERVAL_MS (60s).
    accumulateLogSample();
    if (currentTime - lastSdLogTime >= SD_LOG_INTERVAL_MS || lastSdLogTime == 0) {
      logToSD();
      lastSdLogTime = currentTime;
    }
  }

  // 4. Handle NTP sync independently
  if (!timeSynchronized) {
    if (currentTime - lastNtpSyncAttempt >= 60000 || lastNtpSyncAttempt == 0) {
      updateNTPTime();
    }
  }

  // 5. Keep WiFi alive (starts OTA + web UI on a late or re-connect), then
  //    service them once they exist
  maintainWiFi();
  if (netServicesStarted) {
    ArduinoOTA.handle();
    server.handleClient();
  }
  yield();
}

// ===========================================================================
//  BSEC3 + BME690 forced-mode driver (cooperative; adapted from Bosch's
//  bsec_integration.c). Replaces the BSEC2 callback model.
// ===========================================================================

// I2C glue mapping the bme69x API onto the Arduino Wire bus.
static BME69X_INTF_RET_TYPE bmeI2cRead(uint8_t reg, uint8_t *data, uint32_t len, void *intf) {
  uint8_t addr = *(uint8_t*)intf;
  Wire.beginTransmission(addr);
  Wire.write(reg);
  if (Wire.endTransmission(false) != 0) return BME69X_E_COM_FAIL;
  if (Wire.requestFrom((int)addr, (int)len) != len) return BME69X_E_COM_FAIL;
  for (uint32_t i = 0; i < len; i++) data[i] = Wire.read();
  return BME69X_INTF_RET_SUCCESS;
}
static BME69X_INTF_RET_TYPE bmeI2cWrite(uint8_t reg, const uint8_t *data, uint32_t len, void *intf) {
  uint8_t addr = *(uint8_t*)intf;
  Wire.beginTransmission(addr);
  Wire.write(reg);
  for (uint32_t i = 0; i < len; i++) Wire.write(data[i]);
  return (Wire.endTransmission() == 0) ? BME69X_INTF_RET_SUCCESS : BME69X_E_COM_FAIL;
}
static void bmeDelayUs(uint32_t period, void *intf) { delayMicroseconds(period); }

static void logBsec(const char* what, int rc) {
  if (rc != BSEC_OK) Serial.println("[BSEC] " + String(what) + " rc=" + String(rc));
}

void setupBsec() {
  memset(&bme, 0, sizeof(bme));
  bme.read = bmeI2cRead;
  bme.write = bmeI2cWrite;
  bme.delay_us = bmeDelayUs;
  bme.intf = BME69X_I2C_INTF;
  bme.intf_ptr = &bmeI2cAddr;
  bme.amb_temp = 25;

  int8_t brc = bme69x_init(&bme);
  if (brc != BME69X_OK)
    Serial.println("[BME690] init failed rc=" + String(brc));
  else
    Serial.println("[BME690] init OK, variant-ID=0x" + String(bme.variant_id, HEX) + " (0x02 = BME690)");

  logBsec("init", bsec_init(bsecInst));

  bsec_version_t v;
  if (bsec_get_version(bsecInst, &v) == BSEC_OK)
    Serial.println("[BSEC] v" + String(v.major) + "." + String(v.minor) + "." +
                   String(v.major_bugfix) + "." + String(v.minor_bugfix));

  logBsec("set_configuration",
          bsec_set_configuration(bsecInst, bsec_config_iaq, BSEC_MAX_PROPERTY_BLOB_SIZE,
                                 bsecWorkBuffer, sizeof(bsecWorkBuffer)));

  loadBsecState();

  bsec_sensor_configuration_t requested[7];
  bsec_sensor_configuration_t required[BSEC_MAX_PHYSICAL_SENSOR];
  uint8_t nRequired = BSEC_MAX_PHYSICAL_SENSOR;
  const float rate = BSEC_SAMPLE_RATE_LP;
  uint8_t i = 0;
  requested[i].sensor_id = BSEC_OUTPUT_RAW_PRESSURE;                        requested[i++].sample_rate = rate;
  requested[i].sensor_id = BSEC_OUTPUT_IAQ;                                 requested[i++].sample_rate = rate;
  requested[i].sensor_id = BSEC_OUTPUT_STATIC_IAQ;                          requested[i++].sample_rate = rate;
  requested[i].sensor_id = BSEC_OUTPUT_CO2_EQUIVALENT;                      requested[i++].sample_rate = rate;
  requested[i].sensor_id = BSEC_OUTPUT_TVOC_EQUIVALENT;                     requested[i++].sample_rate = rate;
  requested[i].sensor_id = BSEC_OUTPUT_SENSOR_HEAT_COMPENSATED_TEMPERATURE; requested[i++].sample_rate = rate;
  requested[i].sensor_id = BSEC_OUTPUT_SENSOR_HEAT_COMPENSATED_HUMIDITY;    requested[i++].sample_rate = rate;
  logBsec("update_subscription",
          bsec_update_subscription(bsecInst, requested, i, required, &nRequired));
}

static void parseBsecOutputs(const bsec_output_t* out, uint8_t n) {
  for (uint8_t i = 0; i < n; i++) {
    switch (out[i].sensor_id) {
      case BSEC_OUTPUT_RAW_PRESSURE:                        currentPress = out[i].signal; break;
      case BSEC_OUTPUT_IAQ:
        currentIAQ = out[i].signal; currentIAQAccuracy = out[i].accuracy; break;
      case BSEC_OUTPUT_STATIC_IAQ:                          currentStaticIAQ = out[i].signal; break;
      case BSEC_OUTPUT_CO2_EQUIVALENT:                      currentCO2 = out[i].signal; break;
      case BSEC_OUTPUT_TVOC_EQUIVALENT:                     currentVOC = out[i].signal; break;
      case BSEC_OUTPUT_SENSOR_HEAT_COMPENSATED_TEMPERATURE: currentTemp = out[i].signal; break;
      case BSEC_OUTPUT_SENSOR_HEAT_COMPENSATED_HUMIDITY:    currentHum = out[i].signal; break;
      default: break;
    }
  }
}

void bsec3Run() {
  int64_t now = (int64_t)millis() * INT64_C(1000000);   // ns
  if (now < bsecNextCallNs) return;

  bsec_bme_settings_t s;
  memset(&s, 0, sizeof(s));
  if (bsec_sensor_control(bsecInst, now, &s) != BSEC_OK) return;
  bsecNextCallNs = s.next_call;

  if (!s.trigger_measurement || s.op_mode == BME69X_SLEEP_MODE) return;

  struct bme69x_conf conf;
  if (bme69x_get_conf(&conf, &bme) != BME69X_OK) return;
  conf.os_hum  = s.humidity_oversampling;
  conf.os_temp = s.temperature_oversampling;
  conf.os_pres = s.pressure_oversampling;
  if (bme69x_set_conf(&conf, &bme) != BME69X_OK) return;

  struct bme69x_heatr_conf hconf;
  memset(&hconf, 0, sizeof(hconf));
  hconf.enable     = BME69X_ENABLE;
  hconf.heatr_temp = s.heater_temperature;
  hconf.heatr_dur  = s.heater_duration;
  if (bme69x_set_heatr_conf(BME69X_FORCED_MODE, &hconf, &bme) != BME69X_OK) return;
  if (bme69x_set_op_mode(BME69X_FORCED_MODE, &bme) != BME69X_OK) return;

  uint32_t durUs = bme69x_get_meas_dur(BME69X_FORCED_MODE, &conf, &bme) +
                   (uint32_t)s.heater_duration * 1000U;
  delay(durUs / 1000U + 1U);

  struct bme69x_data data;
  uint8_t nFields = 0;
  if (bme69x_get_data(BME69X_FORCED_MODE, &data, &nFields, &bme) != BME69X_OK || nFields == 0)
    return;

  // In FPU mode (BME69X_USE_FPU) the readings are already deg C / %RH / Pa / Ohm.
#ifdef BME69X_USE_FPU
  float tIn = data.temperature, hIn = data.humidity;
#else
  float tIn = data.temperature / 100.0f, hIn = data.humidity / 1024.0f;
#endif

  bsec_input_t in[BSEC_MAX_PHYSICAL_SENSOR];
  uint8_t n = 0;
  if (BSEC_CHECK_INPUT(s.process_data, BSEC_INPUT_HEATSOURCE)) {
    in[n].sensor_id = BSEC_INPUT_HEATSOURCE; in[n].signal = 0.0f; in[n].time_stamp = now; n++;
  }
  if (BSEC_CHECK_INPUT(s.process_data, BSEC_INPUT_TEMPERATURE)) {
    in[n].sensor_id = BSEC_INPUT_TEMPERATURE; in[n].signal = tIn; in[n].time_stamp = now; n++;
  }
  if (BSEC_CHECK_INPUT(s.process_data, BSEC_INPUT_HUMIDITY)) {
    in[n].sensor_id = BSEC_INPUT_HUMIDITY; in[n].signal = hIn; in[n].time_stamp = now; n++;
  }
  if (BSEC_CHECK_INPUT(s.process_data, BSEC_INPUT_PRESSURE)) {
    in[n].sensor_id = BSEC_INPUT_PRESSURE; in[n].signal = data.pressure; in[n].time_stamp = now; n++;
  }
  if (BSEC_CHECK_INPUT(s.process_data, BSEC_INPUT_GASRESISTOR) && (data.status & BME69X_GASM_VALID_MSK)) {
    in[n].sensor_id = BSEC_INPUT_GASRESISTOR; in[n].signal = data.gas_resistance; in[n].time_stamp = now; n++;
  }
  if (n == 0) return;

  bsec_output_t out[BSEC_NUMBER_OUTPUTS];
  uint8_t nOut = BSEC_NUMBER_OUTPUTS;
  if (bsec_do_steps(bsecInst, in, n, out, &nOut) == BSEC_OK) {
    parseBsecOutputs(out, nOut);
    newDataAvailable = true;
  }
}

// --- Helper Functions ---
String buildBsecDebugString() {
  String log = "Time:" + String(millis() / 1000) + "s";
  log += ", IAQ:" + String(currentIAQ);
  log += " (" + String(currentIAQAccuracy) + ")"; 
  log += ", sIAQ:" + String(currentStaticIAQ);
  log += ", CO2eq:" + String(currentCO2);
  log += ", bVOC:" + String(currentVOC);
  log += ", Temp:" + String(currentTemp) + "C"; 
  log += ", Hum:" + String(currentHum) + "%";    
  log += ", Pres:" + String(currentPress / 100.0) + "hPa";
  log += ", Lux:" + String(currentLux, 1);
  log += ", Snd:" + String(currentSoundLevel) + " peak:" + String(currentSoundPeak) + " dB:" + String(currentSoundDb, 1);
  log += ", Bat:" + String(currentBatteryVolts, 2) + "V (" + String(currentBatteryPercent) + "%)";
  return log;
}

void handleErrorCondition(void) {
  Serial.println("[FATAL] Unrecoverable error. Halting.");
  while (true) {
    digitalWrite(ERROR_LED_PIN, HIGH);
    delay(100);
    digitalWrite(ERROR_LED_PIN, LOW);
    delay(100);
  }
}

void loadBsecState(void) {
  if (EEPROM.read(BSEC_STATE_MAGIC_NUMBER_ADDR) == BSEC_STATE_VALID_MAGIC) {
    Serial.println("[INFO] Valid BSEC state found. Loading...");
    for (uint16_t i = 0; i < BSEC_MAX_STATE_BLOB_SIZE; i++) {
      bsecState[i] = EEPROM.read(BSEC_STATE_EEPROM_ADDR + i);
    }
    logBsec("set_state",
            bsec_set_state(bsecInst, bsecState, BSEC_MAX_STATE_BLOB_SIZE,
                           bsecWorkBuffer, sizeof(bsecWorkBuffer)));
    Serial.println("[INFO] BSEC state loaded.");
  } else {
    Serial.println("[INFO] No valid BSEC state found in EEPROM. Starting fresh.");
  }
}

void saveBsecState(void) {
  uint32_t len = 0;
  int rc = bsec_get_state(bsecInst, 0, bsecState, BSEC_MAX_STATE_BLOB_SIZE,
                          bsecWorkBuffer, sizeof(bsecWorkBuffer), &len);
  if (rc != BSEC_OK || len == 0) { logBsec("get_state", rc); return; }

  Serial.println("[INFO] Saving BSEC state to EEPROM...");
  for (uint16_t i = 0; i < len; i++) {
    EEPROM.write(BSEC_STATE_EEPROM_ADDR + i, bsecState[i]);
  }
  EEPROM.write(BSEC_STATE_MAGIC_NUMBER_ADDR, BSEC_STATE_VALID_MAGIC);

  if (EEPROM.commit()) {
    Serial.println("[INFO] BSEC state saved successfully (" + String(len) + " bytes).");
    lastBsecStateSaveTime = millis();
  } else {
    Serial.println("[ERROR] Failed to commit BSEC state to EEPROM.");
  }
}

void handleBsecStateSaving(void) {
  bool readyToSave = (currentIAQAccuracy >= 3); 

  if (readyToSave) {
    if (millis() - lastBsecStateSaveTime >= BSEC_STATE_SAVE_INTERVAL_MS) {
      saveBsecState();
    }
  }
}

void connectToWiFi() {
  Serial.print("[INFO] Connecting to WiFi: ");
  Serial.println(ssid);
  WiFi.setAutoReconnect(true);   // let the stack heal brief AP dropouts itself
  WiFi.begin(ssid, password);
  int retries = 0;
  while (WiFi.status() != WL_CONNECTED && retries < 30) { 
    delay(500); Serial.print("."); retries++;
  }

  if (WiFi.status() == WL_CONNECTED) {
    Serial.println("\n[INFO] WiFi connected!");
    Serial.print("[INFO] IP Address: "); Serial.println(WiFi.localIP());
  } else {
    Serial.println("\n[ERROR] Failed to connect to WiFi.");
  }
}

// Keep the WiFi link alive without ever blocking the sensor loop. Starts the
// network services (OTA + web UI) on the first successful connection —
// whether that happens at boot or hours later because the router was down —
// and kicks off a non-blocking reconnect attempt every WIFI_RETRY_INTERVAL_MS
// while the link stays down.
void maintainWiFi() {
  if (WiFi.status() == WL_CONNECTED) {
    if (!netServicesStarted) {
      Serial.print("[INFO] WiFi up, IP: "); Serial.println(WiFi.localIP());
      setupOTA();
      setupWebServer();
      netServicesStarted = true;
    }
    return;
  }

  if (lastWifiRetry != 0 && millis() - lastWifiRetry < WIFI_RETRY_INTERVAL_MS) return;
  lastWifiRetry = millis();
  Serial.println("[WiFi] Link down - retrying connection...");
  WiFi.disconnect();
  WiFi.begin(ssid, password);
}

void setupOTA() {
  ArduinoOTA.setHostname(OTA_HOSTNAME);
  ArduinoOTA.begin();
  Serial.println("[OTA] Ready. Hostname: " + String(OTA_HOSTNAME));
}

// Convert WiFi RSSI (dBm) to an approximate 0-100% quality.
int rssiToPercent(long rssi) {
  if (rssi <= -100) return 0;
  if (rssi >= -50)  return 100;
  return 2 * (int)(rssi + 100);
}

// Short human label for the current signal strength.
const char* wifiQualityLabel(long rssi) {
  if (rssi >= -55) return "Excellent";
  if (rssi >= -65) return "Good";
  if (rssi >= -75) return "Fair";
  if (rssi >= -85) return "Weak";
  return "Poor";
}

// ===========================================================================
//  SD data logging (CSV). Averages the ~20 BSEC samples between writes into a
//  single 60s row. Timestamps use bootEpoch + uptime so a session that syncs
//  NTP at any point gets absolute time for all of its rows (see updateNTPTime).
// ===========================================================================

// Monotonic seconds since boot, immune to the 49-day millis() rollover.
int64_t uptimeSeconds() { return esp_timer_get_time() / 1000000LL; }

// Read, increment, and persist the boot counter. 0xFFFFFFFF (blank EEPROM) -> 0.
uint32_t nextBootId() {
  uint32_t id = 0;
  EEPROM.get(BOOT_ID_EEPROM_ADDR, id);
  if (id == 0xFFFFFFFFUL) id = 0;
  id++;
  EEPROM.put(BOOT_ID_EEPROM_ADDR, id);
  EEPROM.commit();
  return id;
}
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

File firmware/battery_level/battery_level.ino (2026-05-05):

/*
 * ESP32 LiPo Battery Monitor (1M / 1M Voltage Divider)
  */

const int VBAT_ADC_PIN = 1; // Safe ADC pin on ESP32

// Voltage divider configuration
// R1 (Top) = 1M, R2 (Bottom) = 1M
// Ratio = (R1 + R2) / R2 = (1000000 + 1000000) / 1000000 = 2.0
const float DIVIDER_RATIO = 2.0; 

void setup() {
  Serial.begin(115200);
  
  // Set ADC attenuation to 11dB (allows reading up to ~3.1V safely)
  // Since our max divided voltage is 2.1V, this is perfect.
  analogSetAttenuation(ADC_11db); 
  
  Serial.println("Starting Battery Monitor...");
}

void loop() {
  // 1. Take multiple readings and average them to filter out ESP32 ADC noise
  int numSamples = 20;
  uint32_t totalMilliVolts = 0;
  
  for (int i = 0; i < numSamples; i++) {
    // analogReadMilliVolts() is MUCH more accurate than analogRead() 
    // because it uses factory calibration burned into the ESP32 chip.
    totalMilliVolts += analogReadMilliVolts(VBAT_ADC_PIN);
    delay(10); // Short delay between samples
  }
  
  float averageMilliVolts = totalMilliVolts / (float)numSamples;
  
  // 2. Convert to Volts and multiply by the divider ratio to get real battery voltage
  float pinVoltage = averageMilliVolts / 1000.0;
  float batteryVoltage = pinVoltage * DIVIDER_RATIO;
  
  // 3. Convert the voltage to a percentage using the LiPo curve
  int batteryPercentage = getBatteryPercentage(batteryVoltage);

  // 4. Print the results
  Serial.print("Pin Volts: ");
  Serial.print(pinVoltage, 3);
  Serial.print("V | Bat Volts: ");
  Serial.print(batteryVoltage, 3);
  Serial.print("V | Charge: ");
  Serial.print(batteryPercentage);
  Serial.println("%");

  // Wait 2 seconds before the next reading
  delay(2000); 
}

/*
 * Function to map voltage to percentage based on typical LiPo discharge curve
 */
int getBatteryPercentage(float voltage) {
  // If voltage is higher than 4.2, it's fully charged (or plugged into USB)
  if (voltage >= 4.20) return 100;
  
  // Safe lower bound (typical ESP32 3.3V LDO dropout is around 3.3V)
  if (voltage <= 3.30) return 0;

  // Piecewise linear mapping based on LiPo discharge curve
  if (voltage >= 4.00) return mapFloat(voltage, 4.00, 4.20, 85, 100);
  if (voltage >= 3.90) return mapFloat(voltage, 3.90, 4.00, 75, 85);
  if (voltage >= 3.80) return mapFloat(voltage, 3.80, 3.90, 50, 75);
  if (voltage >= 3.70) return mapFloat(voltage, 3.70, 3.80, 25, 50);
  if (voltage >= 3.50) return mapFloat(voltage, 3.50, 3.70, 10, 25);
  
  // Between 3.30V and 3.50V
  return mapFloat(voltage, 3.30, 3.50, 0, 10);
}

/*
 * Helper function: Arduino's built-in map() only works with integers.
 * We need one that works with floats for battery voltages.
 */
int mapFloat(float x, float in_min, float in_max, int out_min, int out_max) {
  return (int)((x - in_min) * (out_max - out_min) / (in_max - in_min) + out_min);
}

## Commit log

2026-05-05 Initial commit: ESP32-S3 BME690 sensor node + dashboard
    [ESP32_BME690.kicad_pcb, ESP32_BME690.kicad_sch, esp32-s3-02.kicad_sch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]
2026-05-06 some changes to improve sound sensor values
2026-05-10 small changes to the kicad script
2026-07-01 Add live WiFi status web page to USB PCB firmware
    Ports the built-in web server from the V3 firmware to the older USB PCB
    node so sensor readings can be viewed in a browser. Adds a WebServer on
    port 80 that serves an auto-refreshing status table (temperature,
    humidity, pressure, IAQ, CO2, VOC, light, sound, battery, WiFi signal),
    started only when WiFi connects and serviced from the main loop.
    The V3-specific charge-profile controls and fuel-gauge rows are omitted
    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
2026-07-01 Add SD data logging to USB PCB firmware + CSV plotting script
    Firmware (ESP32_BME690_usb): log an averaged sensor row once per 60s to
    /datalog.csv on the SD card (SPI CS10/MOSI11/SCLK12/MISO13, own bus). The
    ~20 BSEC samples between writes are averaged; sound keeps avg+peak. Writes
    open/append/close each row so a power cut loses at most one row.
    Timestamps for intermittent-WiFi / NTP-only deployments: each row carries
    boot_id (EEPROM boot counter), uptime_s, epoch and a synced flag. bootEpoch
    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
2026-07-04 Report WiFi signal on the dashboard and fix rooms not rendering
    The dashboard never showed WiFi signal quality because the firmware
    didn't include it in the JSON upload; worse, the room boxes were
    hardcoded to Kitchen/Living_Room, so a node reporting any other
    location (e.g. Hallway) was stored but never displayed.
    - firmware: add rssi (dBm) and wifiPercent to the POSTed payload
    - server: store the WiFi fields; build room boxes dynamically from
    /data so new nodes appear without a server edit; show a WiFi row
    (dBm, %, quality label) per room, with a clear "not reported
    (update firmware)" fallback for nodes on older firmware
    - plot_datalog.py: insert NaN breaks at gaps > --gap-min (defa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
    [ESP32_BME690_usb.ino]
2026-07-04 Recover WiFi automatically and start OTA/web UI on late connect
    Previously OTA and the web server only started if WiFi was connected
    during setup(); a node that booted while the router was down never
    served its status page until a manual reboot.
    - maintainWiFi() runs every loop: on the first successful connection
    (at boot or hours later) it starts OTA + the web server, and while
    the link is down it kicks off a non-blocking reconnect every 30 s
    - enable the WiFi stack's auto-reconnect for brief AP dropouts
    - only service OTA / handleClient once the services actually exist
    - README: document the self-healing behaviour
    Claude-Session: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
    [ESP32_BME690_usb.ino]
